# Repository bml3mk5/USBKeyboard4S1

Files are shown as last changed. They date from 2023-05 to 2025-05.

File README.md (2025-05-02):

# USBキーボード for 日立 MB-S1

## フォルダ構成

    Board/ ......................... 基板設計
      KiCad/ ....................... KiCad Version 6  通常基板(DIPタイプを使用)
      EasyEDA/ ..................... EasyEDA 6.5      小型基板(表面実装)
    Software/ ...................... PICマイコン用ソフトウェア

### [ラズパイPico版はこちら](https://github.com/bml3mk5/USBKeyboard4S1_PiPico)

-----
# USBKeyboard for HITACHI MB-S1

## Folders:

    Board/ ......................... Circuit board design
      KiCad/ ....................... KiCad Version 6  Normal board (using DIP type PIC micro controller)
      EasyEDA/ ..................... EasyEDA 6.5      Small board (using SMT type)
    Software/ ...................... Software for PIC micro controller

### [Raspberry Pi Pico version is here](https://github.com/bml3mk5/USBKeyboard4S1_PiPico)

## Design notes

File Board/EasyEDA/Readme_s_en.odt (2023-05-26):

USBKeyboard for S1 [S]

Designed by Sasaji 2023 Rev. 0.1

This is a converter to connect a USB Keyboard to HITACHI MB-S1 and LimeLight.

You can use a USB Keyboard with a HUB and a simple one.

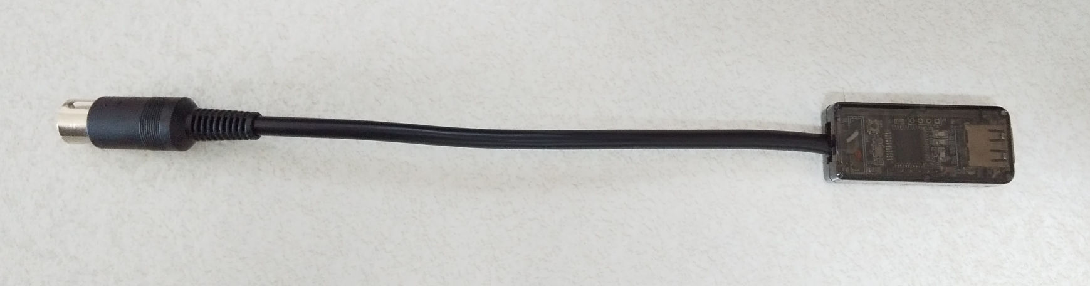
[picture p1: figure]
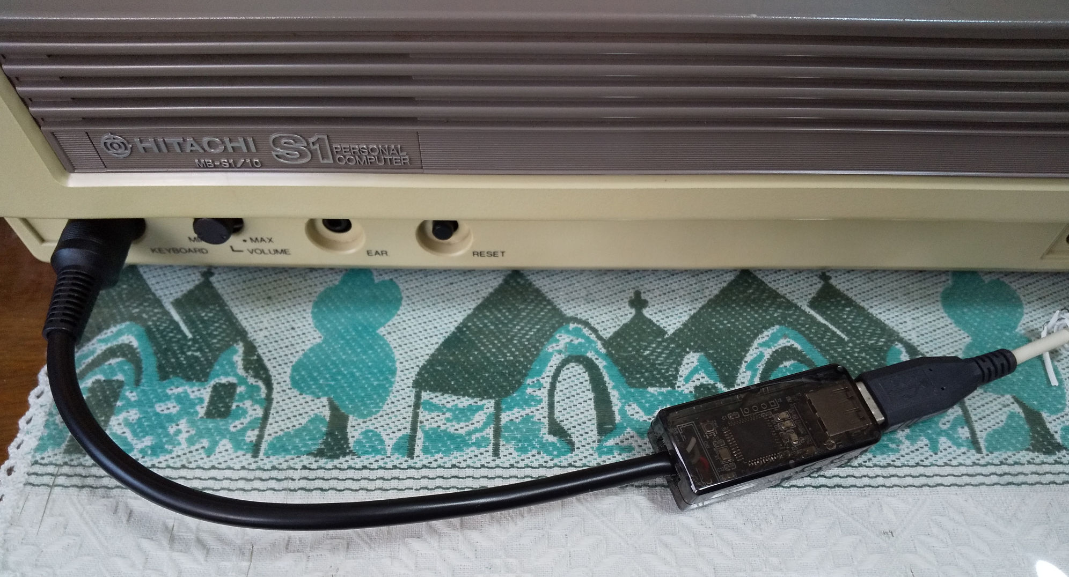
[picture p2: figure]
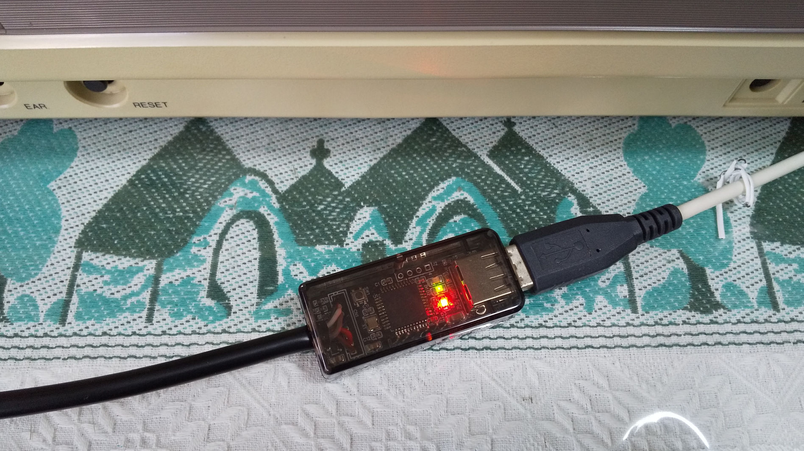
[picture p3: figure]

Example of the connection

Light the LED

# How To Use

1. Turn off the computer MB-S1.
2. Connect this device to the keyboard connector of MB-S1.
3. Connect a USB keyboard to this device.
4. Turn on the MB-S1.

When the USB keyboard is recognized, the green LED blinks about 3 times.

# Key Assign

Key assignment assumes a Japanese keyboard. We also recommend using a full keyboard.

These keys on the MB-S1 that are not on a USB keyboard are assigned as follows:

Table 1: Special key assignments

Key of MB-S1 | Key on USB Keyboard
[BREAK] | [F9]
[COPY] | [F12] / [PrintScreen]
[GRAPH] | [無変換] / [F7] / [Left Command]
[INS] | [Insert] / [F13]
[カタ/ひら] | [カタカナひらがな] / [F8] / [Right Command]
[変換] | [変換] / [F6]
[＿ロ] | [＿ろ] / [F11] / [Right ALT] / [Right Option]
[num ?] | [End]
[num ,] | [Page Down]

# LED on This Converter

# Red LED is ON when katakana is ON.

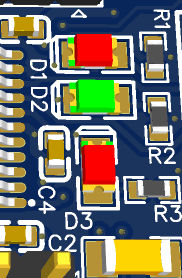
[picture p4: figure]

# Green LED is ON when hiragana is ON. Green LED blinks about 3 times when the USB keyboard is recognized.

# Red LED is ON when caps is ON.

# LED on a USB Keyboard

Num Lock → Turn on when katakana is ON.

Caps Lock → Turn on when caps is ON.

Scroll Lock → Turn on when hiragana is ON.

# The Board Information

UART Connector PIC microcontroller RESET Switch

PICKit Connector

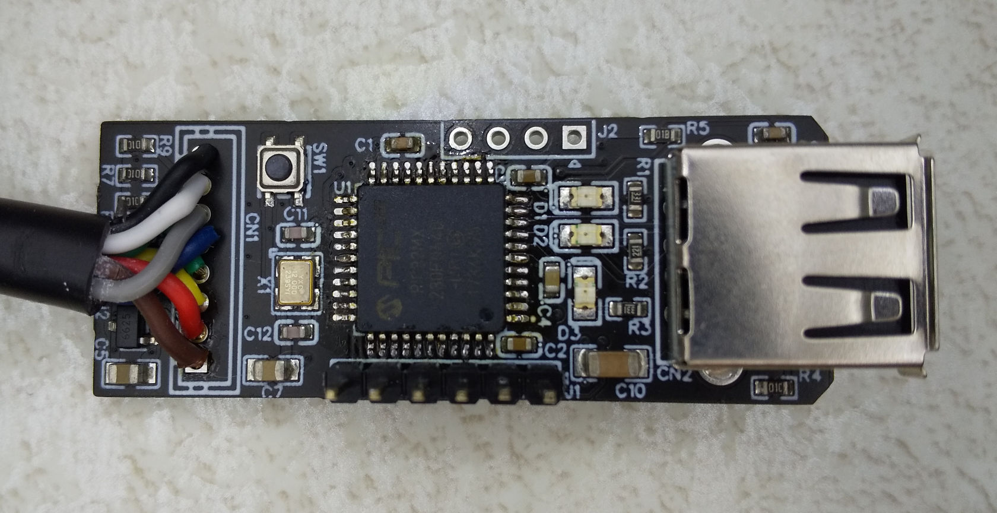
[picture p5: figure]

PIC microcontroller:

PIC32MX230F064D-I/PT

RESET Switch:

Initialize the PIC when you press this switch.

PICKit Connector:

Use for programming to the PIC.

Devices that can be connected are PICKit3, PICKit4 and compatibles.

These terminals are N/C, PGEC, PGED, GND, +3.3V, /MCLR from the left in the photo.

UART Connector:

Use for serial communication with the PIC. Nothing is outputted by default.

These terminals are GND, U1RX, U1TX, +5V from the left in the photo.

# Attention

- You can use only a wired keyboard and one with a HUB.
- Use a keyboard that supports USB1.1.
- This does not support a wireless keyboard or Bluetooth.
- Do not connect anything to ports on a HUB.
- Behavior is undefined when you connect a device other than a keyboard. In the worst case, the device may fail.
- Avoid connecting and disconnecting USB devices while the power is on.
- Do not disconnect this from the computer while the power is on.

# No Warranty

- This device is a prototype. Please note that we do not consider the noise generated during use or deterioration over time.
- We are not responsible for any damage caused by this device.

USE OF THIS EQUIPMENT IS AT YOUR OWN RISK.

# Web

This document and CAD data are available here:

http://s-sasaji.ddo.jp/bml3mk5/ (http://s-sasaji.ddo.jp/bml3mk5/s1usbkb.htm#smd)s1usbkb.htm (http://s-sasaji.ddo.jp/bml3mk5/s1usbkb.htm#smd)# (http://s-sasaji.ddo.jp/bml3mk5/s1usbkb.htm#smd)smd (http://s-sasaji.ddo.jp/bml3mk5/s1usbkb.htm#smd)

or

https://github.com/bml3mk5/USBKeyboard4S1

Sasaji (sasaji@s-sasaji.ddo.jp)

http://s-sasaji.ddo.jp/bml3mk5/

(Twitter: https://twitter.com/bml3mk5)

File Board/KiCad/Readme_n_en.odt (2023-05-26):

USBKeyboard for S1 [N]

Designed by Sasaji 2023 Rev. 0.1

This is a converter to connect a USB Keyboard to HITACHI MB-S1 and LimeLight.

You can use a USB Keyboard with a HUB and a simple one.

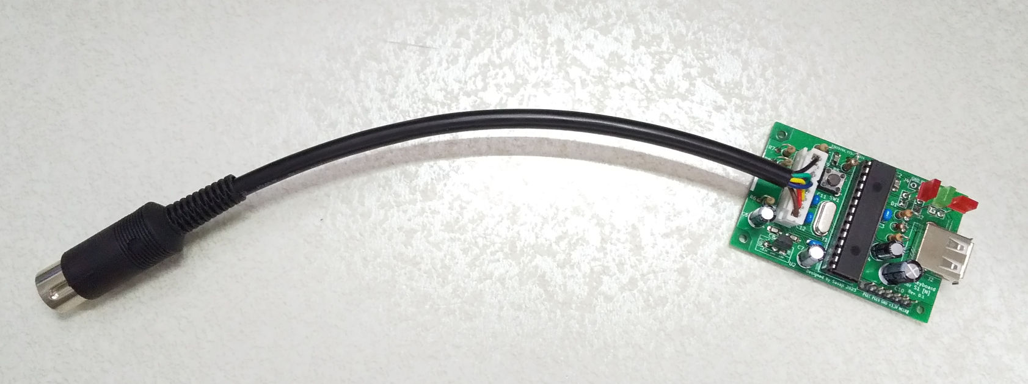
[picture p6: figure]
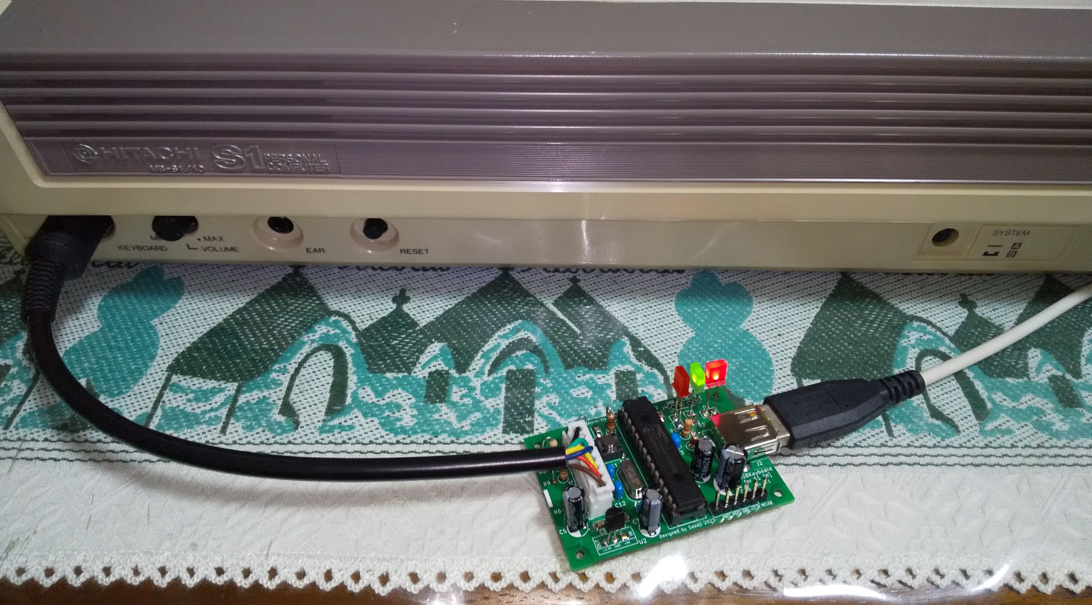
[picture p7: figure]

Example of the connection

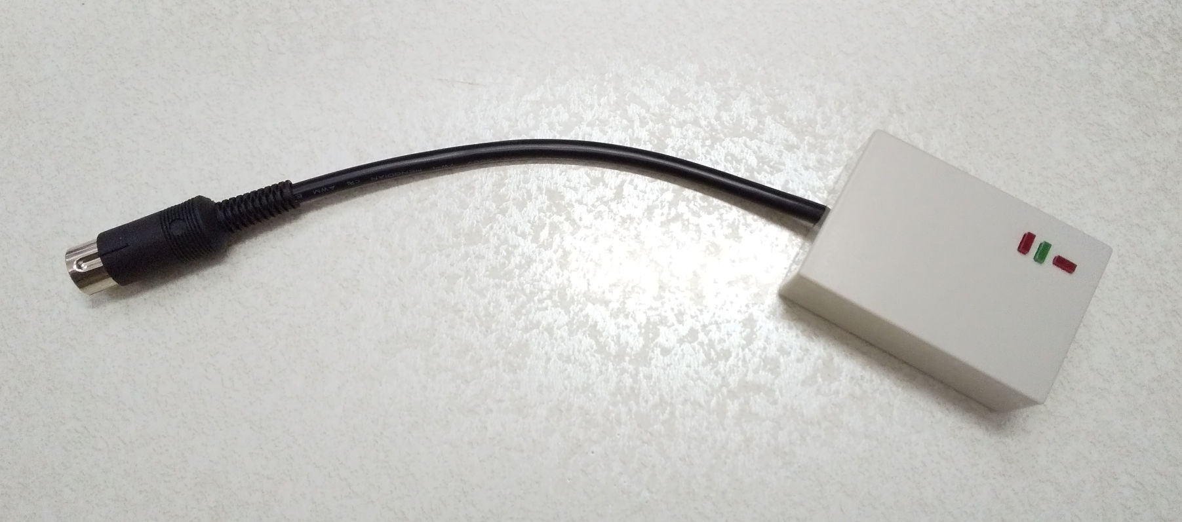
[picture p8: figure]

Housed in a case

# How To Use

1. Turn off the computer MB-S1.
2. Connect this device to the keyboard connector of MB-S1.
3. Connect a USB keyboard to this device.
4. Turn on the MB-S1.

When the USB keyboard is recognized, the green LED blinks about 3 times.

# Key Assign

Key assignment assumes a Japanese keyboard. We also recommend using a full keyboard.

These keys on the MB-S1 that are not on a USB keyboard are assigned as follows:

Table 1: Special key assignments

Key of MB-S1 | Key on USB Keyboard
[BREAK] | [F9]
[COPY] | [F12] / [PrintScreen]
[GRAPH] | [無変換] / [F7] / [Left Command]
[INS] | [Insert] / [F13]
[カタ/ひら] | [カタカナひらがな] / [F8] / [Right Command]
[変換] | [変換] / [F6]
[＿ロ] | [＿ろ] / [F11] / [Right ALT] / [Right Option]
[num ?] | [End]
[num ,] | [Page Down]

# LED on a USB Keyboard

Num Lock → Turn on when katakana is ON.

Caps Lock → Turn on when caps is ON.

Scroll Lock → Turn on when hiragana is ON.

# LED on This Converter

# Red LED is ON when katakana is ON.

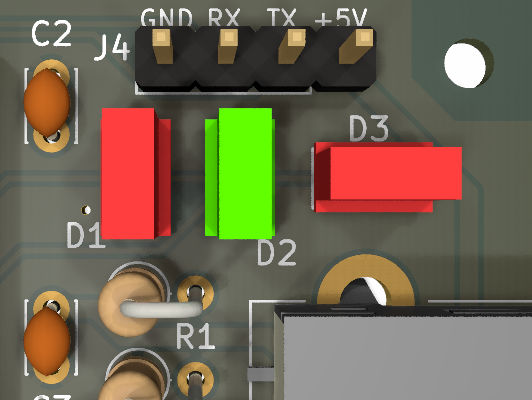
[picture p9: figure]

# Green LED is ON when hiragana is ON. Green LED blinks about 3 times when the USB keyboard is recognized.

# Red LED is ON when caps is ON.

# The Board Information

UART Connector PIC microcontroller RESET Switch

PICKit Connector

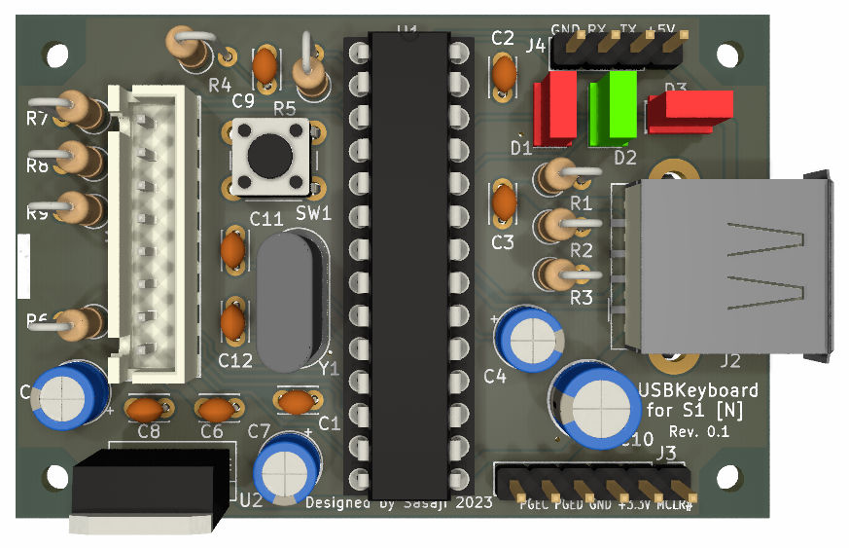
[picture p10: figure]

PIC microcontroller:

PIC32MX230F064B

RESET Switch:

Initialize the PIC when you press this switch.

PICKit Connector:

Use for programming to the PIC.

Devices that can be connected are PICKit3, PICKit4 and compatibles.

These terminals are N/C, PGEC, PGED, GND, +3.3V, /MCLR from the left in the photo.

UART Connector:

Use for serial communication with the PIC. Nothing is outputted by default.

These terminals are GND, U1RX, U1TX, +5V from the left in the photo.

# Attention

- You can use only a wired keyboard and one with a HUB.
- Use a keyboard that supports USB1.1.
- This does not support a wireless keyboard or Bluetooth.
- Do not connect anything to ports on a HUB.
- Behavior is undefined when you connect a device other than a keyboard. In the worst case, the device may fail.
- Avoid connecting and disconnecting USB devices while the power is on.
- Do not disconnect this from the computer while the power is on.

# No Warranty

- This device is a prototype. Please note that we do not consider the noise generated during use or deterioration over time.
- We are not responsible for any damage caused by this device.
  USE OF THIS EQUIPMENT IS AT YOUR OWN RISK.

# Web

This document and CAD data are available here:

http://s-sasaji.ddo.jp/bml3mk5/ (http://s-sasaji.ddo.jp/bml3mk5/s1usbkb.htm#board)s1usbkb.htm (http://s-sasaji.ddo.jp/bml3mk5/s1usbkb.htm#board)# (http://s-sasaji.ddo.jp/bml3mk5/s1usbkb.htm#board)board (http://s-sasaji.ddo.jp/bml3mk5/s1usbkb.htm#board)

or

https://github.com/bml3mk5/USBKeyboard4S1

Sasaji (sasaji@s-sasaji.ddo.jp)

http://s-sasaji.ddo.jp/bml3mk5/

(Twitter: https://twitter.com/bml3mk5)

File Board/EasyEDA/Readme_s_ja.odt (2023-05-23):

USBキーボード for S1 [S]

Designed by Sasaji 2023 Rev. 0.1

日立MB-S1または来夢来人とUSBキーボードを接続するための変換装置です。

USB Aコネクタのついたキーボードおよびハブ付きキーボードを接続することができます。


本体との接続例

LEDを点灯させたところ

# 使い方

1. MB-S1実機の電源をOFFにしてください。
2. 本装置をMB-S1実機のキーボード端子に接続してください。
3. 本装置にUSBキーボードを接続してください。
4. MB-S1実機の電源をONにしてください。

USBキーボードを認識すると緑色のLEDが3回ほど点滅します。

# キー操作

キーアサインは日本語キーボードを前提にしています。

また、フルキーボードの使用を推奨します。

S1にあってUSBキーボードにないキーについては以下のように割当てています。

表 1: 特殊なキーの割当て

S1側のキー | USBキーボード
[BREAK] | [F9]
[COPY] | [F12] / [PrintScreen]
[GRAPH] | [無変換] / [F7] / [左Command]
[INS] | [Insert] / [F13]
[カタ/ひら] | [カタカナひらがな] / [F8] / [右Command]
[変換] | [変換] / [F6]
[＿ロ] | [＿ろ] / [F11] / [右ALT] / [右Option]
[テンキー ?] | [End]
[テンキー ,] | [Page Down]

# 基板上のLED

# カタカナONのとき 赤色点灯


# ひらがなONのとき 緑色点灯 また、USBキーボードを 認識した時に 3回ほど点滅します。

# Caps ONのとき 赤色点灯

# キーボード側のLED

Num Lock → カタカナONのとき点灯

Caps Lock → Caps ONのとき点灯

Scroll Lock → ひらがなONのとき点灯

# ボードの情報

UART端子 PICマイコン RESETスイッチ

PICKit接続端子


PICマイコン

PIC32MX230F064D-I/PTを使用。

RESETスイッチ

押すとマイコンを初期状態に戻します。

PICKit接続端子

PICマイコンにプログラムを書き込む場合に使用します。

接続できる装置はPICKit3 / PICKit4 およびその互換機です。

端子は、写真左からN/C, PGEC, PGED, GND, +3.3V, /MCLR となります。

UART端子

PICマイコンとシリアル通信する場合に使用します。デフォルトでは何も出力されません。

端子は、写真左からGND, U1RX, U1TX, +5Vとなります。

# ご注意

- 対応しているのは有線のキーボード単体およびハブ付きキーボードです。
- USB1.1に対応しているキーボードを使用してください。
- 無線キーボードやBluetoothには対応していません。
- ハブのポートにはなにも接続しないでください。
- キーボード以外のデバイスを接続した時の動作は不定です。最悪デバイスが故障する可能性があります。
- 電源が入っている間はUSBデバイスの抜き差しはなるべく避けてください。
- 電源が入っている間はこの装置をパソコン本体から外さないでください。

# 免責事項

- この装置は試作品です。使用中に発生するノイズや経年劣化などに対しての考慮は全くしていませんので予めご了承ください。
- この装置によって発生したいかなる損害についても当方は一切責任を負いません。

この装置を使用するにあたってはすべて自己責任で行ってください。

# Webページ

この資料やCADデータなどを置いています。

http://s-sasaji.ddo.jp/bml3mk5/ (http://s-sasaji.ddo.jp/bml3mk5/s1usbkb.htm#smd)s1usbkb.htm (http://s-sasaji.ddo.jp/bml3mk5/s1usbkb.htm#smd)# (http://s-sasaji.ddo.jp/bml3mk5/s1usbkb.htm#smd)smd (http://s-sasaji.ddo.jp/bml3mk5/s1usbkb.htm#smd)

または

https://github.com/bml3mk5/USBKeyboard4S1

連絡先：

Sasaji (sasaji@s-sasaji.ddo.jp)

http://s-sasaji.ddo.jp/bml3mk5/

(Twitter: https://twitter.com/bml3mk5)

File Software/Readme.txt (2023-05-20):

==============================================================================
    USBキーボード -> MB-S1キーボード変換

 Copyright(C) Sasaji 2018-2023 All Rights Reserved.
==============================================================================

● 準備するもの

  マイコン: PIC32MX230F064B (DIP/SOP 28ピン)
  マイコンにプログラムできる装置(PICKit3,PICKit4など)

● 使い方

    dist/PIC32MX230F064B/production/USBKeyboard4S1.X.production.hex を、
  MPLAB IPEなどでマイコンに書き込んでください。

    ビルドは、MPLAB X Ver.6.05を使用しました。
      コンパイラ：XC32 v4.21

● キー操作

  キーアサインは日本語キーボードを前提にしています。
  また、フルキーボードの使用を推奨します。

  S1にあってUSBキーボードにないキーについては以下のように割当てています。

  S1側          USBキーボード
  ------------- ---------------------------------------
  [BREAK]       [F9]
  [COPY]        [F12] / [PrintScreen]
  [GRAPH]       [無変換] / [F7] / [左Command]
  [INS]         [Insert] / [F13]
  [カタ/ひら]   [カタカナひらがな] / [F8] / [右Command]
  [変換]        [変換] / [F6]
  [＿ロ]        [＿ろ] / [F11] / [右ALT] / [右Option]
  [テンキー ?]  [End]
  [テンキー ,]  [Page Down]

● キーボードLED

  Num Lock    → カタカナのとき点灯
  Caps Lock   → Caps ONのとき点灯
  Scroll Lock → ひらがなのとき点灯

● ご注意

  ・対応しているのは有線のキーボード単体およびハブ付きキーボードです。
  ・USB1.1に対応しているキーボードを使用してください。
  ・無線キーボードやBluetoothには対応していません。
  ・ハブのポートにはなにも接続しないでください。
  ・電源が入っている状態でのUSBデバイス抜き差しはなるべく避けてください。
  ・キーボード以外のデバイスを接続した時の動作は不定です。最悪デバイスが
    故障する可能性があります。

● 変更履歴

Version 0.2
	ハブ付きキーボードに対応
	英語キーボードにないキーを別のキーに割り当てた。
Version 0.1
	初期

● 免責事項

・このソースの著作権は作者Sasajiにあります。
・このソースコードを使用して発生するいかなる結果も著作権者は一切責任を負いません。
・雑誌やネットなどに転載される場合、不特定多数の方に再配布を行う場合でも
  承諾の必要はありませんが、転載の旨をご連絡いただけたら幸いです。

==============================================================================

連絡先：
  Sasaji (sasaji@s-sasaji.ddo.jp)
    http://s-sasaji.ddo.jp/bml3mk5/

==============================================================================

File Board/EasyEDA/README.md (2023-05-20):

## 使い方：

  1. EasyEADエディタ上で、ドキュメントを開く: File -> Open -> EasyEDA...
  2. jsonファイルを選択して開く。ファイルのインポートを選択。
  3. 別名で保存する -> 保存先のプロジェクトを選択。

----------
## How to use：

  1. On EasyEDA editor, open the document via: File -> Open -> EasyEDA...
  2. Select the json file and import the file, then open it on the editor.
  3. Save As... -> Select a project to save it.

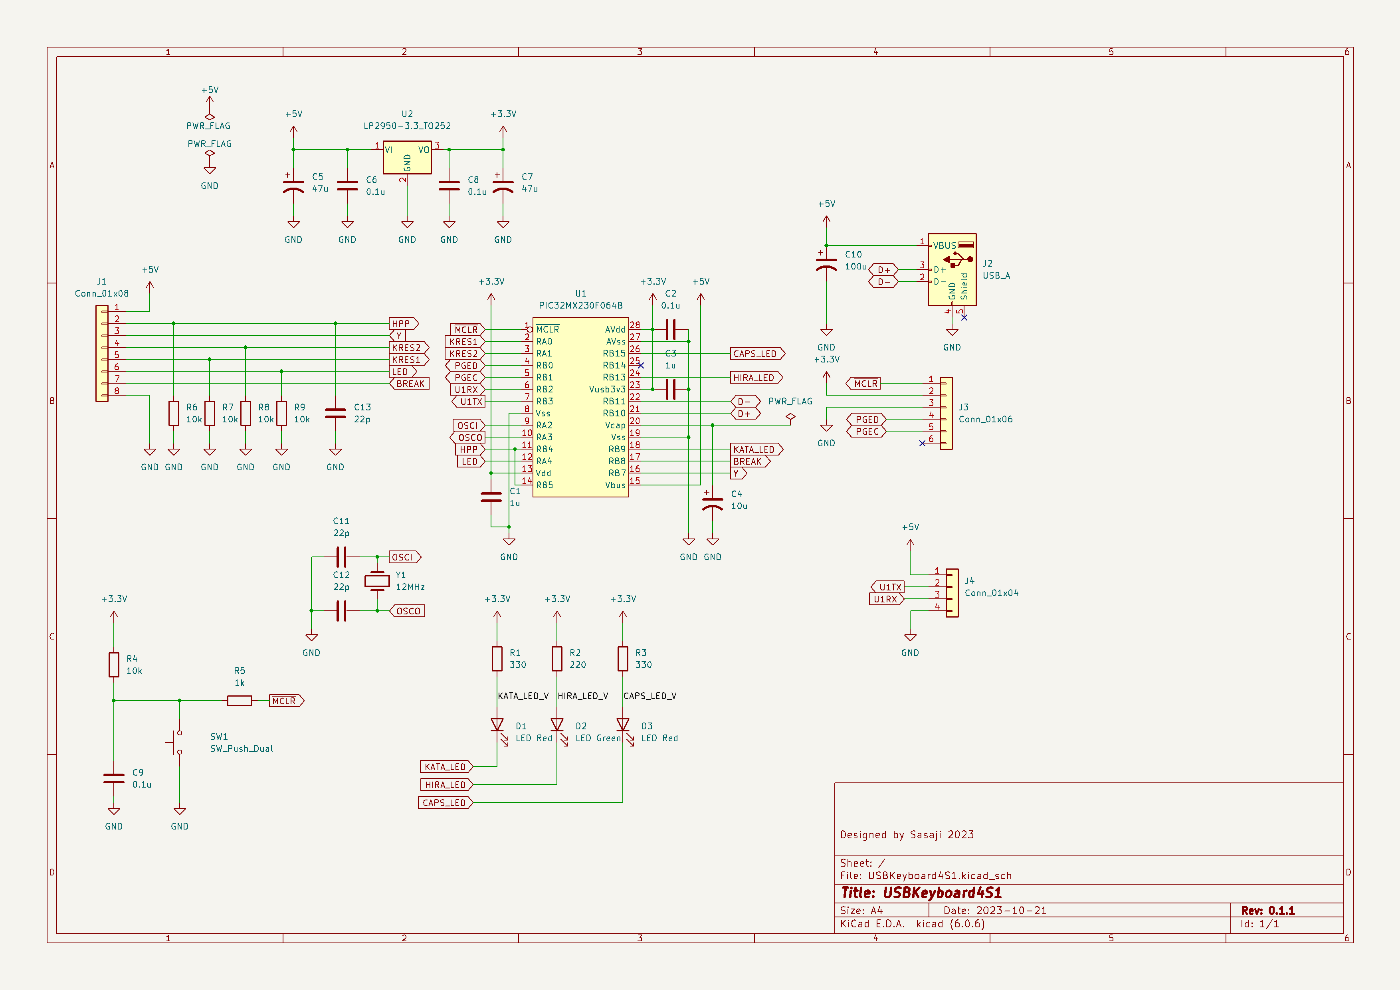
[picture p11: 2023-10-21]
Board/KiCad/Schematic.png

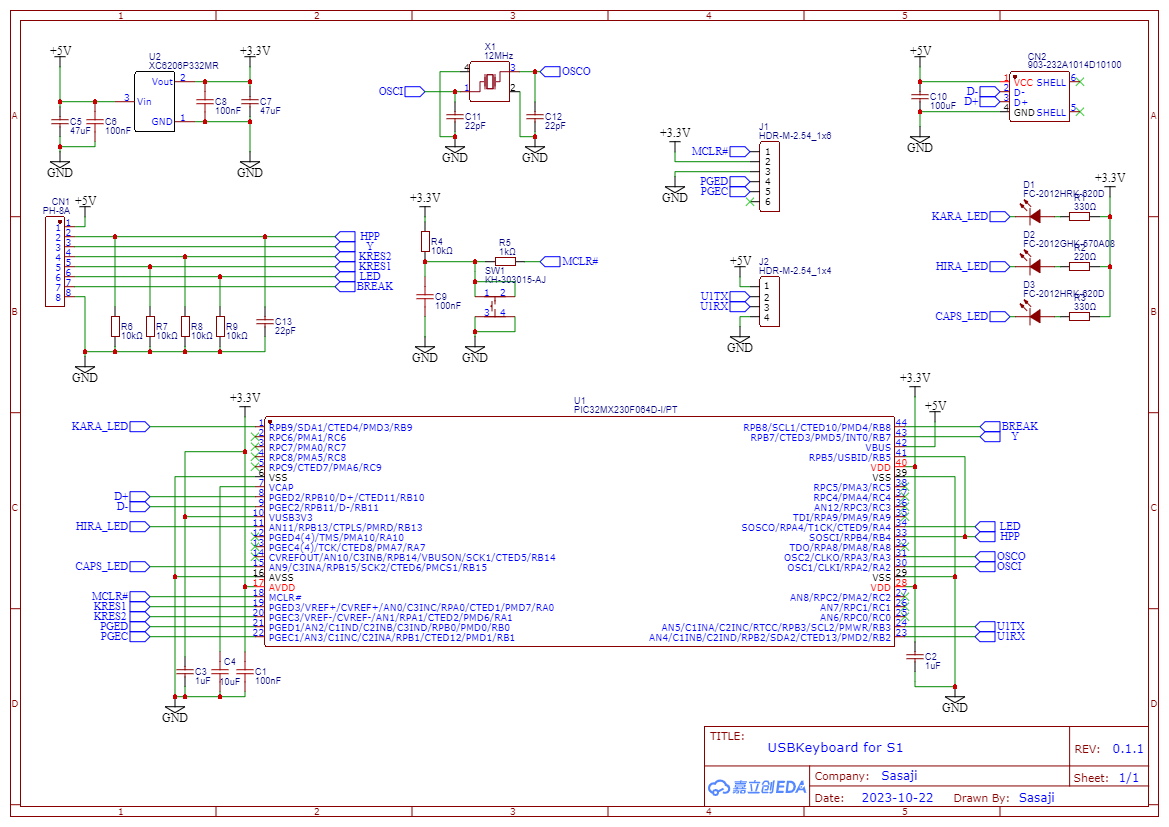
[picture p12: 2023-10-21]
Board/EasyEDA/Schematic.png

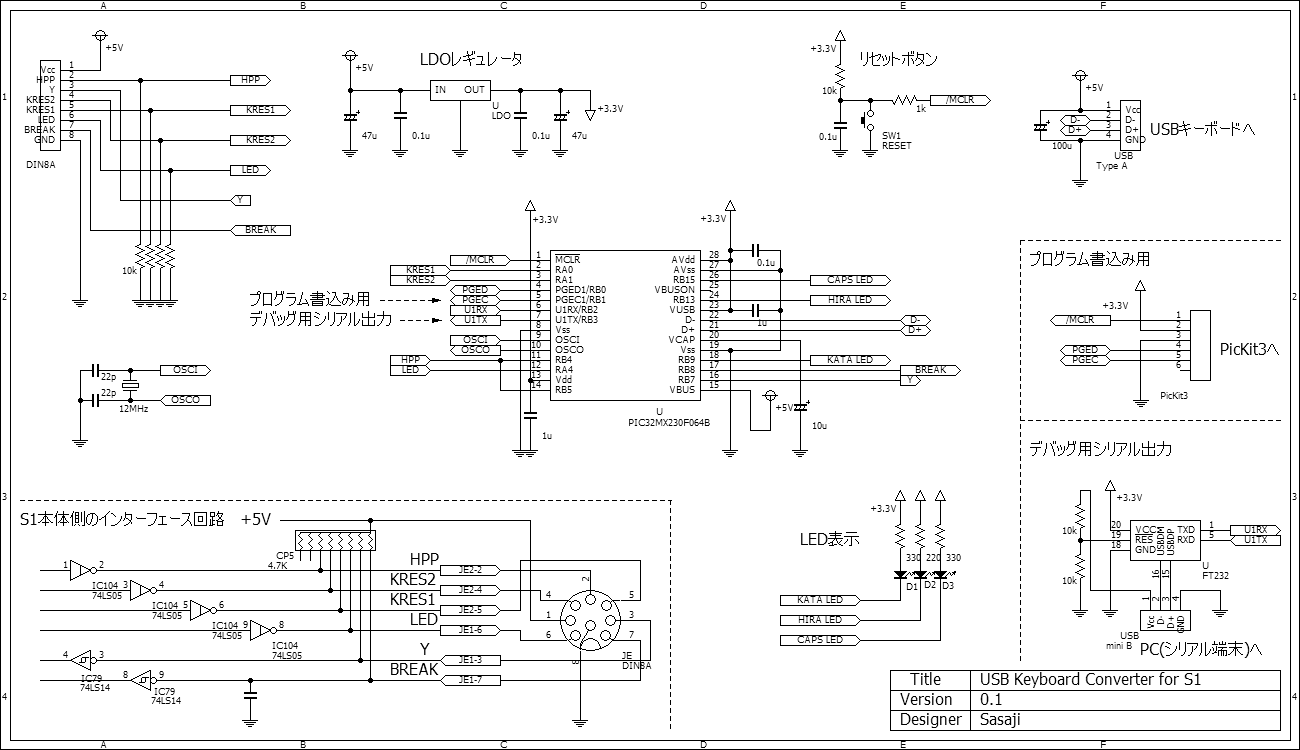
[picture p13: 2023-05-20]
Software/USBKeyboard4S1.X/Design/Circuit.png

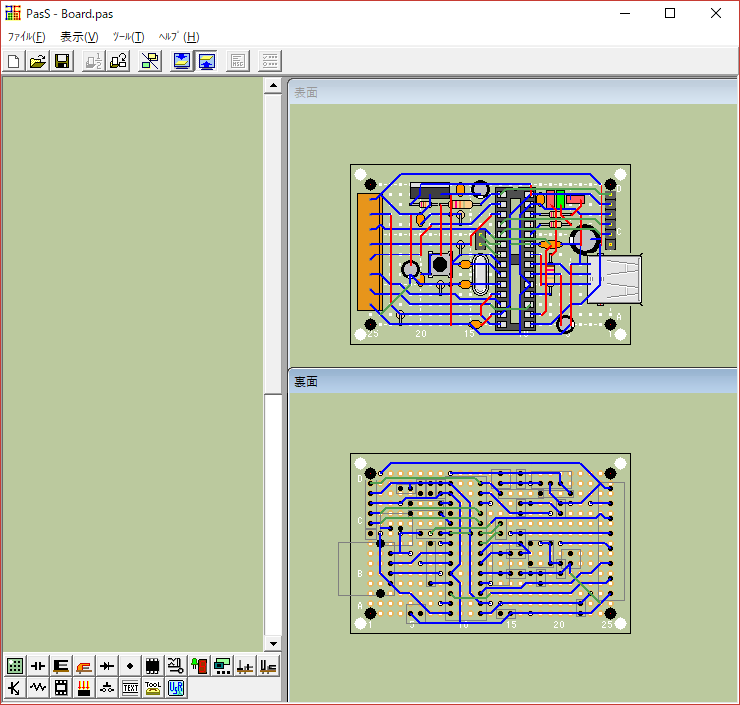
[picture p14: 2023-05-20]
Software/USBKeyboard4S1.X/Design/Board.png

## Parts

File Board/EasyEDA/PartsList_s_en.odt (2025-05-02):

USBKeyboard for S1 [S]

Designed by Sasaji 2023 Rev. 0.1.1

# Parts List

Parts Number | Parts Name | Qty. | Description | Usage
C1, C6, C8, C9 | Ceramic Capacitor | 4 | 0.1uF 0603mil | Bypass
C2, C3 | Ceramic Capacitor | 2 | 1uF 0603mil | Bypass
C4 | Ceramic Capacitor | 1 | 10uF 10V~ 0603mil | Bypass
C5, C7 | Ceramic Capacitor | 2 | 47uF 10V~ 0805mil | Bypass
C10 | Ceramic Capacitor | 1 | 100uF 10V~ 1206mil | Bypass
C11, C12 | Ceramic Capacitor | 2 | 22pF 0603mil | For clock
C13 | Ceramic Capacitor | 1 | 22pF 0603mil | Noise Removal
D1, D3 | LED (Red Color) | 2 | 0805mil
D2 | LED (Green Color) | 1 | 0805mil
J2 | USB A Connector | 1 | For circuit board
R1, R3 | Carbon Resistor | 2 | 330Ω 1/6W~ 0603mil | For Red LED
R2 | Carbon Resistor | 1 | 220Ω 1/6W~ 0603mil | For Green LED
R5 | Carbon Resistor | 1 | 1kΩ 1/6W~ 0603mil | Reset
R4 | Carbon Resistor | 1 | 10kΩ 1/6W~ 0603mil | Pullup
R6, R7, R8, R9 | Carbon Resistor | 4 | 10kΩ 1/6W~ 0603mil | Pulldown
SW1 | Tact Switch | 1 | 4pins 3.4 x 3.4mm Momentary | Reset
U1 | Pic Microcontroller | 1 | PIC32MX230F064D-I/PT TQFP 44
U2 | LDO Regurator | 1 | 5V to 3.3V SOT-23
Y1 | Crystal | 1 | 12MHz 4pins 3.2 x 2.5mm
J1 | Connector 6pins | 1 | Pinheader 1 x 6pins 2.54mm pitch | For PicKit
| DIN connector 8pins | 1 | 8pins Type A male (MP-018 etc.) | Connect to a PC.
| Multicore Cable | 1 | 8cores AWM24 or 26 Outer diameter is less than 6mm. [^1]

  Optional Parts

Parts Number | Parts Name | Qty. | Description | Usage
J2 | Connector 4pins | 1 | Pinheader 1 x 4pins 2.54mm pitch | For UART
| Case | 1 | 53 x 24 x 14mm (AK-N-12)

DIN8pins male assign:

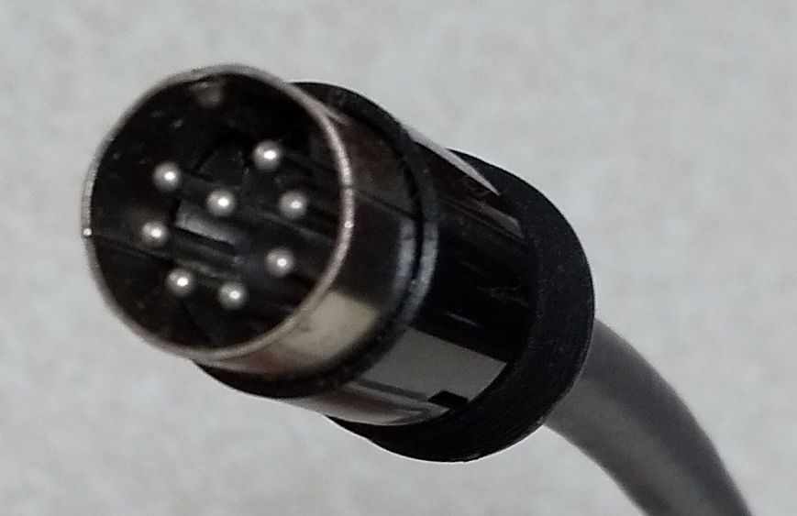
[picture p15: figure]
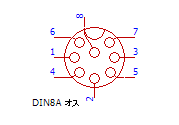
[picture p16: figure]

# Warnings when housing the board in a case

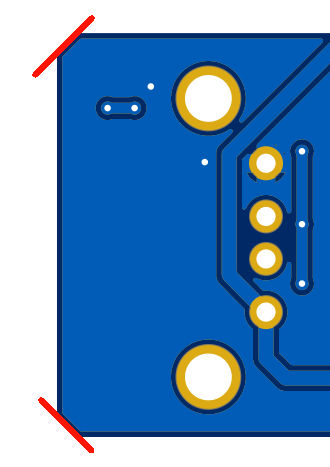
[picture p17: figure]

1. If the board does not fit in the case, cut off the slanted part a little.
2. You must connect the multicore cable directly to the board. If you use a PH connector, it will not fit in a case due to its height.
3. The height of the component side of the board should be about 8.5mm, and the height of the solder side should be about 1.5mm. (When thickness of the board is 1.6mm)

# How to Program to The Microcontroller

1. Connect a Programmer and Power supply to the circuit board.
  a. Connect a programmer (PICKit3/4) to J1 on the board.
  b. Connect a +5V Power supply to J2 or USB connector. When use the USB connector, don’t connect to the data line (D+,D-).

+5V Power Supply: USB Connector or J2 Connector

Programmer (PICKit3/4)


2. Program to PIC microcontroller using MPLAB IPE.
- Select a Device: PIC32MX230F064D
- Select a HEX file:

USBKeyboard4S1.X\dist\PIC32MX230F064D_I\production\USBKeyboard4S1.X.production.hex

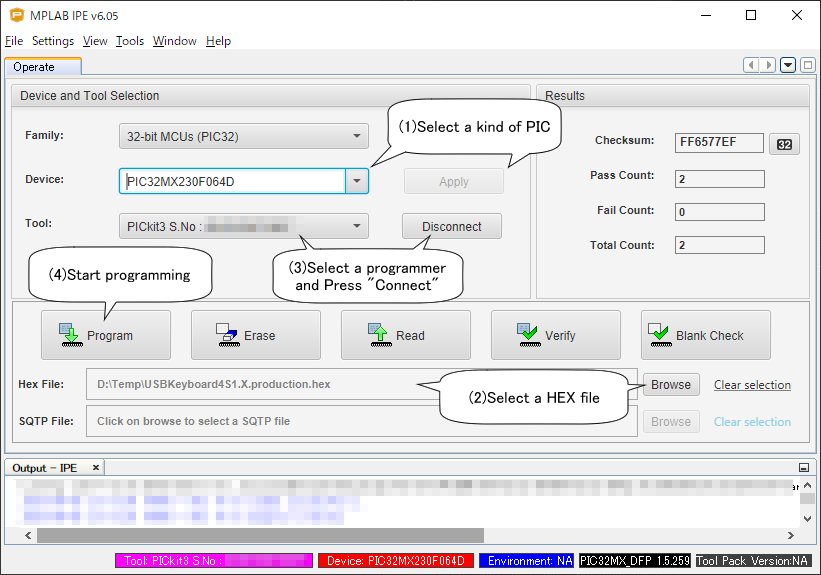
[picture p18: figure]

If succeed the programming, The Red LED(Caps) on the board is brighten.

# Web

There are this document and a CAD data on the web:

http://s-sasaji.ddo.jp/bml3mk5/ (http://s-sasaji.ddo.jp/bml3mk5/s1usbkb.htm#smd)s1usbkb.htm (http://s-sasaji.ddo.jp/bml3mk5/s1usbkb.htm#smd)# (http://s-sasaji.ddo.jp/bml3mk5/s1usbkb.htm#smd)smd (http://s-sasaji.ddo.jp/bml3mk5/s1usbkb.htm#smd)

or

https://github.com/bml3mk5/USBKeyboard4S1

Sasaji (sasaji@s-sasaji.ddo.jp)

http://s-sasaji.ddo.jp/bml3mk5/

(Twitter: https://twitter.com/bml3mk5)

[^1] If the outer diameter is more than 6mm , it will not pass in a bush of a DIN connector.

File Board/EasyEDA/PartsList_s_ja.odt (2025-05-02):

USBキーボード for S1 [S]

Designed by Sasaji 2023 Rev. 0.1.1

# 部品表

番号 | 部品名 | 数量 | 値など | 用途
C1, C6, C8, C9 | セラミックコンデンサ | 4 | 0.1uF 0603mil | パスコン
C2, C3 | セラミックコンデンサ | 2 | 1uF 0603mil | パスコン
C4 | セラミックコンデンサ | 1 | 10uF 10V以上 0603mil | パスコン
C5, C7 | セラミックコンデンサ | 2 | 47uF 10V以上 0805mil | パスコン
C10 | セラミックコンデンサ | 1 | 100uF 10V以上 1206mil | パスコン
C11, C12 | セラミックコンデンサ | 2 | 22pF 0603mil | クロック生成
C13 | セラミックコンデンサ | 1 | 22pF 0603mil | ノイズ対策
D1, D3 | LED 赤色 | 2 | 0805mil
D2 | LED 緑色 | 1 | 0805mil
J2 | USB Aコネクタ | 1 | 基板取付用
R1, R3 | カーボン抵抗 | 2 | 330Ω 1/6W～ 0603mil | 赤LED用
R2 | カーボン抵抗 | 1 | 220Ω 1/6W～ 0603mil | 緑LED用
R5 | カーボン抵抗 | 1 | 1kΩ 1/6W～ 0603mil | リセット用
R4 | カーボン抵抗 | 1 | 10kΩ 1/6W～ 0603mil | プルアップ
R6, R7, R8, R9 | カーボン抵抗 | 4 | 10kΩ 1/6W～ 0603mil | プルダウン
SW1 | タクトスイッチ | 1 | 4ピン 3.4 x 3.4mm モーメンタリ | リセット
U1 | Picマイコン | 1 | PIC32MX230F064D-I/PT TQFP 44ピン
U2 | LDOリニアレギュレータ | 1 | 5V→ 3.3Vのもの SOT-23
Y1 | 水晶振動子 | 1 | 12MHz 4ピン 3.2 x 2.5mm
J1 | コネクタ 6ピン | 1 | ピンヘッダ 1 x 6ピン 2.54mmピッチ | PicKit接続端子
| DINコネクタ 8ピン | 1 | 8ピンAタイプ オス | 本体との接続
| 多芯ケーブル | 1 | 8芯 AWM24か26ぐらい 外径6mm未満[^1]

  以下はオプション

番号 | 部品名 | 数量 | 値など | 用途
J2 | コネクタ 4ピン | 1 | ピンヘッダ 1 x 4ピン 2.54mmピッチ | UART端子
| プラスチックケース | 1 | 53 x 24 x 14mm (秋月電子 AK-N-12 または Aitendo USBコネクタ適合プラケース [C53X24X14]) | 基板収納用

DIN8ピン オスのピン配置は以下になります。


# ケースに収める場合の注意点


1. 基板がケースに収まらない場合は、斜め部分を少し削ってください。
2. 多芯ケーブルは基板に直接接続してください。PHコネクタを使うと高さがあるためケースに収まらなくなります。
3. 基板の部品面の高さは8.5mmほど、ハンダ面の高さは1.5mmほどに収めてください。（基板の厚さを1.6mmとしたとき）

# マイコンへのプログラム方法

1. 基板に電源と書き込み装置を接続してください。
  a. J1端子に書き込み装置(PICKit3/4など)を接続してください。
  b. +5V電源をUSB端子またはJ2端子にある+5VとGNDに接続してください。USB端子を使用する場合、データライン(D+,D-)には接続しないようにしてください。

+5V電源は USB端子 または J2端子 を使用

書き込み装置 (PICKit3/4など)


2. MPLAB IPEなどを使用してマイコンにプログラムしてください。
- PICマイコンはPIC32MX230F064Dを選択。
- HEXファイルは

USBKeyboard4S1.X\dist\PIC32MX230F064D_I\production\USBKeyboard4S1.X.production.hex

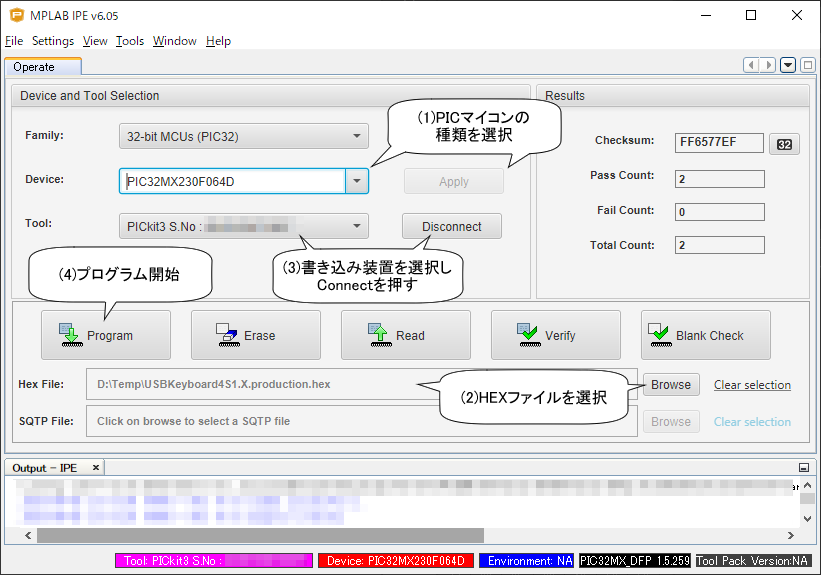
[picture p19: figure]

成功すると、基板上の赤色LED(Caps)が点灯します。

# Webページ

この資料やCADデータなどを置いています。

http://s-sasaji.ddo.jp/bml3mk5/ (http://s-sasaji.ddo.jp/bml3mk5/s1usbkb.htm#smd)s1usbkb.htm (http://s-sasaji.ddo.jp/bml3mk5/s1usbkb.htm#smd)# (http://s-sasaji.ddo.jp/bml3mk5/s1usbkb.htm#smd)smd (http://s-sasaji.ddo.jp/bml3mk5/s1usbkb.htm#smd)

または

https://github.com/bml3mk5/USBKeyboard4S1

連絡先：

Sasaji (sasaji@s-sasaji.ddo.jp)

http://s-sasaji.ddo.jp/bml3mk5/

(Twitter: https://twitter.com/bml3mk5)

[^1] 外径が6mmを超えるとDINコネクタのブッシュを通らなくなります。

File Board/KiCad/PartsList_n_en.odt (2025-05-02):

USBKeyboard for S1 [N]

Designed by Sasaji 2023 Rev. 0.1.1

# Parts List

Parts Number | Parts Name | Qty. | Description | Usage
C2, C6, C8, C9 | Ceramic Capacitor | 4 | 0.1uF | Bypass
C1, C3 | Ceramic Capacitor | 2 | 1uF | Bypass
C4 | Electrolytic Capacitor | 1 | 10uF 10V~ | Bypass
C5, C7 | Electrolytic Capacitor | 2 | 47uF 10V~ | Bypass
C10 | Electrolytic Capacitor | 1 | 100uF 10V~ | Bypass
C11, C12 | Ceramic Capacitor | 2 | 22pF | For clock
C13 | Ceramic Capacitor | 1 | 22pF | Noise Removal
D1, D3 | LED (Red Color) | 2 | Rectangle 2 x 5 x 7mm
D2 | LED (Green Color) | 1 | Rectangle 2 x 5 x 7mm
J2 | USB A Connector | 1 | For circuit board
R1, R3 | Carbon Resistor | 2 | 330Ω 1/4W | For Red LED
R2 | Carbon Resistor | 1 | 220Ω 1/4W | For Green LED
R5 | Carbon Resistor | 1 | 1kΩ 1/4W | Reset
R4 | Carbon Resistor | 1 | 10kΩ 1/4W | Pullup
R6, R7, R8, R9 | Carbon Resistor | 4 | 10kΩ 1/4W | Pulldown
SW1 | Tact Switch | 1 | 6 x 5mm Momentary | Reset
U1 | Pic Microcontroller | 1 | PIC32MX230F064B [^1] DIP 28
U2 | LDO Regurator | 1 | 5V→ 3.3V / 100mA (LM2940,LP2950 etc.)
Y1 | Crystal | 1 | 12MHz
J1 | Connector 8pins | 1 | JST XH 1 x 8pins 2.5mm pitch male | Connect between a cable and the board. * It’s not necessary if connect a cable directly.
| Connector 8pins Housing | 1 | JST XH 1 x 8pins 2.5mm pitch female
| Pins | 8 | For XH connector
J3 | Connector 6pins | 1 | Pinheader 1 x 6pins 2.54mm pitch | For PicKit
| DIN connector 8pins | 1 | 8pins Type A male (MP-018 etc.) | Connect to a PC.
| Multicore Cable | 1 | 8cores AWM24 or 26 Outer diameter is less than 6mm. [^2]

Optional Parts

Parts Number | Parts Name | Qty. | Description | Usage
J4 | Connector 4pins | 1 | Pinheader 1 x 4pins 2.54mm pitch | For UART
| IC Socket | 1 | DIP 28 300mil
| Case | 1 | 45 x 65mm (TAKACHI SW-65 etc.)
| Screws | 4 | M2 x 8mm
| Nuts | 4
| Washers | 4

DIN8pins male assign:


# How to Program to The Microcontroller

1. Connect a Programmer and Power supply to the circuit board.
  a. Connect a programmer (PICKit3/4) to J3 on the board.
  b. Connect a +5V Power supply to J4 or USB connector. When use the USB connector, don’t connect to the data line (D+,D-).


Programmer (PICKit3/4) +5V Power supply: USB connector or J4 connector

2. Program to PIC microcontroller using MPLAB IPE.
- Select a Device: PIC32MX230F064B
- Select a HEX file:

USBKeyboard4S1.X\dist\PIC32MX230F064B\production\USBKeyboard4S1.X.production.hex

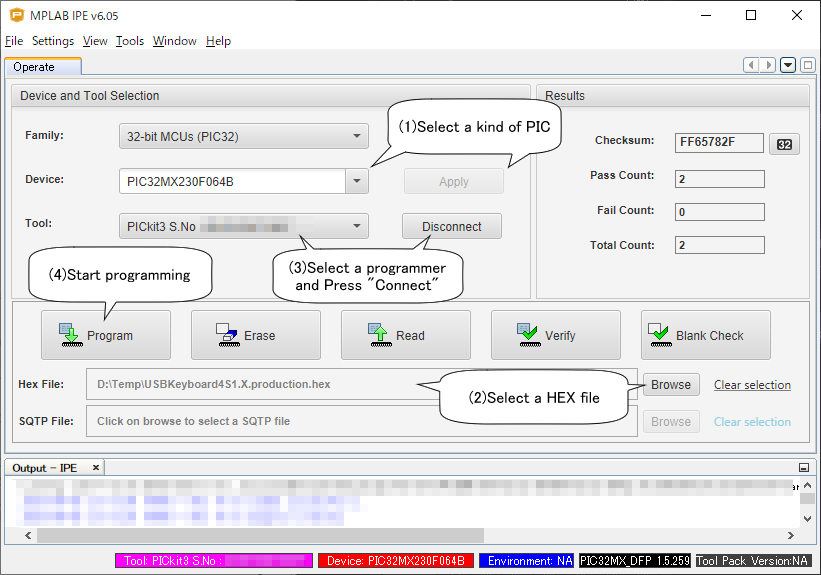
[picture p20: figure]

If succeed the programming, The Red LED(Caps) on the board is brighten.

# Web

There are this document and a CAD data on the web:

http://s-sasaji.ddo.jp/bml3mk5/ (http://s-sasaji.ddo.jp/bml3mk5/s1usbkb.htm#board)s1usbkb.htm (http://s-sasaji.ddo.jp/bml3mk5/s1usbkb.htm#board)# (http://s-sasaji.ddo.jp/bml3mk5/s1usbkb.htm#board)board (http://s-sasaji.ddo.jp/bml3mk5/s1usbkb.htm#board)

or

https://github.com/bml3mk5/USBKeyboard4S1

Sasaji (sasaji@s-sasaji.ddo.jp)

http://s-sasaji.ddo.jp/bml3mk5/

(Twitter: https://twitter.com/bml3mk5)

[^1] You can use PIC32MX2xxFxxxB series.
[^2] If the outer diameter is more than 6mm , it will not pass in a bush of a DIN connector.

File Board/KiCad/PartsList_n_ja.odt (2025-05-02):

USBキーボード for S1 [N]

Designed by Sasaji 2023 Rev. 0.1.1

# 部品表

番号 | 部品名 | 数量 | 値など | 用途
C2, C6, C8, C9 | セラミックコンデンサ | 4 | 0.1uF | パスコン
C1, C3 | セラミックコンデンサ | 2 | 1uF | パスコン
C4 | 電解コンデンサ | 1 | 10uF 10V以上 | パスコン
C5, C7 | 電解コンデンサ | 2 | 47uF 10V以上 | パスコン
C10 | 電解コンデンサ | 1 | 100uF 10V以上 | パスコン
C11, C12 | セラミックコンデンサ | 2 | 22pF | クロック生成
C13 | セラミックコンデンサ | 1 | 22pF | ノイズ対策
D1, D3 | LED 赤色 | 2 | 角型 2 x 5 x 7mm
D2 | LED 緑色 | 1 | 角型 2 x 5 x 7mm
J2 | USB Aコネクタ | 1 | 基板取付用
R1, R3 | カーボン抵抗 | 2 | 330Ω 1/4W | 赤LED用
R2 | カーボン抵抗 | 1 | 220Ω 1/4W | 緑LED用
R5 | カーボン抵抗 | 1 | 1kΩ 1/4W | リセット用
R4 | カーボン抵抗 | 1 | 10kΩ 1/4W | プルアップ
R6, R7, R8, R9 | カーボン抵抗 | 4 | 10kΩ 1/4W | プルダウン
SW1 | タクトスイッチ | 1 | 6 x 5mm モーメンタリ | リセット
U1 | Picマイコン | 1 | PIC32MX230F064B[^1] DIP 28ピン
U2 | LDO 3端子レギュレータ | 1 | 5V→ 3.3Vのもの100mA (LM2940,LP2950など)
Y1 | 水晶振動子 | 1 | 12MHz
J1 | コネクタ 8ピン | 1 | JST XHコネクタ 1 x 8ピン 2.5mmピッチ オス | 多芯ケーブルと基板との接続 ※多芯ケーブルを直接基板に取り付ける場合は不要。
| コネクタ 8ピン ハウジング | 1 | JST XHコネクタ 1 x 8ピン 2.5mmピッチ メス
| コネクタ用ピン | 8 | 上記XHコネクタ用ピン
J3 | コネクタ 6ピン | 1 | ピンヘッダ 1 x 6ピン 2.54mmピッチ | PicKit接続端子
| DINコネクタ 8ピン | 1 | 8ピンAタイプ オス (マル信無線電機MP-018など) | 本体との接続
| 多芯ケーブル | 1 | 8芯 AWM24か26ぐらい 外径 6mm未満[^2]

以下はオプション

番号 | 部品名 | 数量 | 値など | 用途
J4 | コネクタ 4ピン | 1 | ピンヘッダ 1 x 4ピン 2.54mmピッチ | UART端子
| ICソケット | 1 | DIP 28ピン 300mil
| プラスチックケース | 1 | 45 x 65mm (タカチ SW-65など) | 基板収納用
| なべ小ねじ | 4 | M2 x 8mm以上 | 基板をケースに固定
| ナット | 4 | 上記ネジ用
| ワッシャ | 4 | 上記ネジ用

DIN8ピン オスのピン配置は以下になります。


# マイコンへのプログラム方法

1. 基板に電源と書き込み装置を接続してください。
  a. J3端子に書き込み装置(PICKit3/4など)を接続してください。
  b. +5V電源をUSB端子またはJ4端子にある+5VとGNDに接続してください。USB端子を使用する場合、データライン(D+,D-)には接続しないようにしてください。


書き込み装置 (PICKit3/4など) +5V電源は USB端子 または J4端子 を使用

2. MPLAB IPEなどを使用してマイコンにプログラムしてください。
- PICマイコンはPIC32MX230F064Bを選択。
- HEXファイルは

USBKeyboard4S1.X\dist\PIC32MX230F064B\production\USBKeyboard4S1.X.production.hex

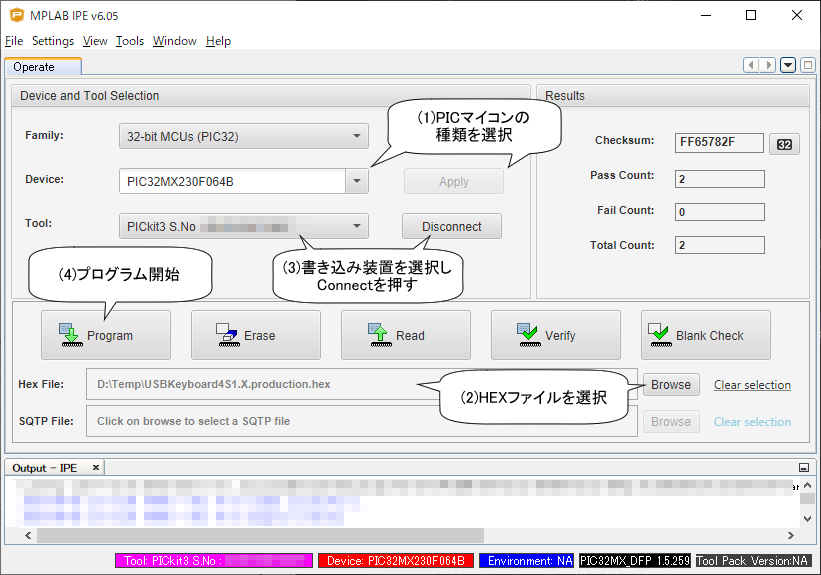
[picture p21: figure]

成功すると、基板上の赤色LED(Caps)が点灯します。

# Webページ

この資料やCADデータなどを置いています。

http://s-sasaji.ddo.jp/bml3mk5/ (http://s-sasaji.ddo.jp/bml3mk5/s1usbkb.htm#board)s1usbkb.htm (http://s-sasaji.ddo.jp/bml3mk5/s1usbkb.htm#board)# (http://s-sasaji.ddo.jp/bml3mk5/s1usbkb.htm#board)board (http://s-sasaji.ddo.jp/bml3mk5/s1usbkb.htm#board)

または

https://github.com/bml3mk5/USBKeyboard4S1

連絡先：

Sasaji (sasaji@s-sasaji.ddo.jp)

http://s-sasaji.ddo.jp/bml3mk5/

(Twitter: https://twitter.com/bml3mk5)

[^1] PIC32MX2xxFxxxBシリーズが使用できます。
[^2] 外径が6mmを超えるとDINコネクタのブッシュを通らなくなります。

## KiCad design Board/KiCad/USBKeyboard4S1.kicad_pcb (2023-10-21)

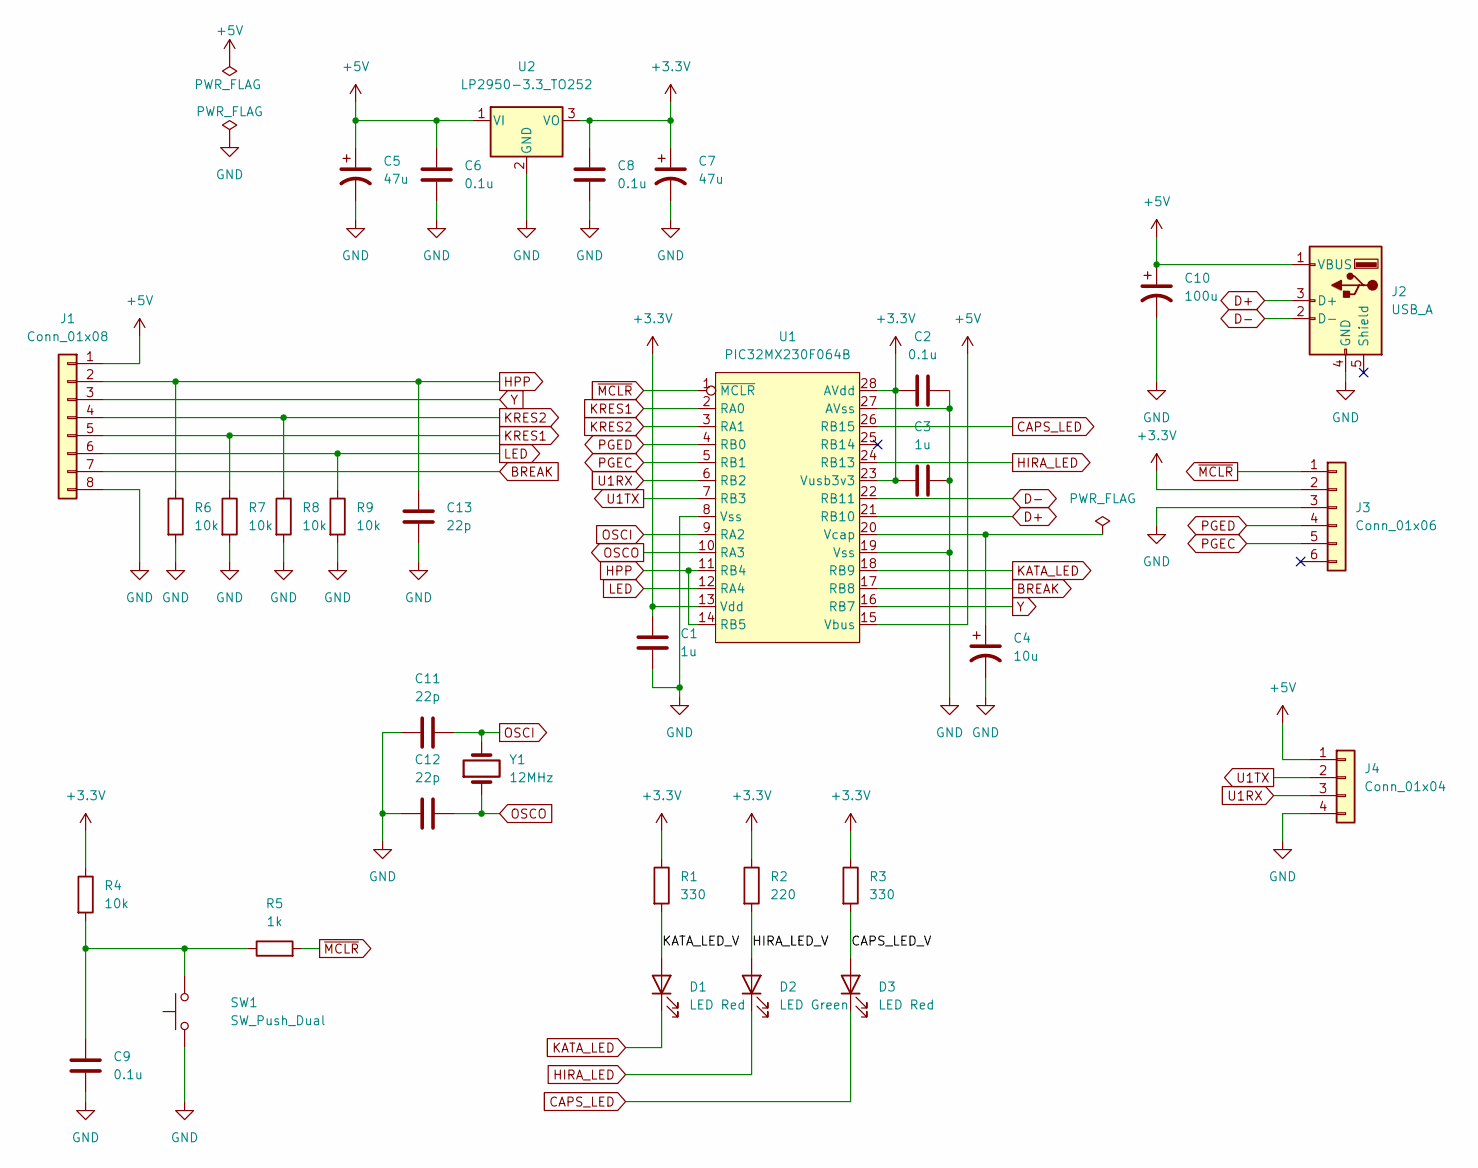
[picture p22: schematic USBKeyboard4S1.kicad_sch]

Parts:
C1, C3: 1u; C_Disc_D3.0mm_W2.0mm_P2.50mm
C2, C6, C8, C9: 0.1u; C_Disc_D3.0mm_W2.0mm_P2.50mm
C4: 10u; CP_Radial_D5.0mm_P2.50mm
C5, C7: 47u; CP_Radial_D5.0mm_P2.50mm
C10: 100u; CP_Radial_D6.3mm_P2.50mm
C11, C12, C13: 22p; C_Disc_D3.0mm_W2.0mm_P2.50mm
D1, D3: LED Red; LED_D2.0mm_W4.8mm_H2.5mm_FlatTop
D2: LED Green; LED_D2.0mm_W4.8mm_H2.5mm_FlatTop
J1: Conn_01x08; JST_XH_B8B-XH-A_1x08_P2.50mm_Vertical
J2: USB_A; USB_A_Horizontal
J3: Conn_01x06; PinHeader_1x06_P2.54mm_Vertical
J4: Conn_01x04; PinHeader_1x04_P2.54mm_Vertical
R1, R3: 330; R_Axial_DIN0207_L6.3mm_D2.5mm_P2.54mm_Vertical
R2: 220; R_Axial_DIN0207_L6.3mm_D2.5mm_P2.54mm_Vertical
R4, R6, R7, R8, R9: 10k; R_Axial_DIN0207_L6.3mm_D2.5mm_P2.54mm_Vertical
R5: 1k; R_Axial_DIN0207_L6.3mm_D2.5mm_P2.54mm_Vertical
SW1: SW_Push_Dual; SW_PUSH_6mm
U1: PIC32MX230F064B; DIP-28_W7.62mm_Socket
U2: LP2950-3.3_TO252; TO-262-3_Vertical
Y1: 12MHz; Crystal_HC18-U_Vertical

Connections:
+3.3V: C1.1, C2.1, C3.1, C7.1, C8.2, J3.2, R1.1, R2.1, R3.1, R4.1, U1.13 (Vdd), U1.23 (Vusb3v3), U1.28 (AVdd), U2.3 (VO)
+5V: C5.1, C6.2, C10.1, J1.1, J2.1 (VBUS), J4.1, U1.15 (Vbus), U2.1 (VI)
/CAPS_LED_V: D3.1 (A), R3.2
/HIRA_LED_V: D2.1 (A), R2.2
/KATA_LED_V: D1.1 (A), R1.2
BREAK: J1.7, U1.17 (RB8)
CAPS_LED: D3.2 (K), U1.26 (RB15)
D+: J2.3 (D+), U1.21 (RB10)
D-: J2.2 (D-), U1.22 (RB11)
GND: C1.2, C2.2, C3.2, C4.2, C5.2, C6.1, C7.2, C8.1, C9.1, C10.2, C11.1, C12.1, C13.1, J1.8, J2.4 (GND), J3.3, J4.4, R6.2, R7.2, R8.2, R9.2, SW1.1, U1.8 (Vss), U1.19 (Vss), U1.27 (AVss), U2.2 (GND)
HIRA_LED: D2.2 (K), U1.24 (RB13)
HPP: C13.2, J1.2, R6.1, U1.11 (RB4), U1.14 (RB5)
KATA_LED: D1.2 (K), U1.18 (RB9)
KRES1: J1.5, R7.1, U1.2 (RA0)
KRES2: J1.4, R8.1, U1.3 (RA1)
LED: J1.6, R9.1, U1.12 (RA4)
unnamed: C4.1, U1.20 (Vcap)
unnamed: C9.2, R4.2, R5.1, SW1.2
OSCI: C11.2, U1.9 (RA2), Y1.2
OSCO: C12.2, U1.10 (RA3), Y1.1
PGEC: J3.5, U1.5 (RB1)
PGED: J3.4, U1.4 (RB0)
U1RX: J4.3, U1.6 (RB2)
U1TX: J4.2, U1.7 (RB3)
Y: J1.3, U1.16 (RB7)
~MCLR: J3.1, R5.2, U1.1 (~MCLR)

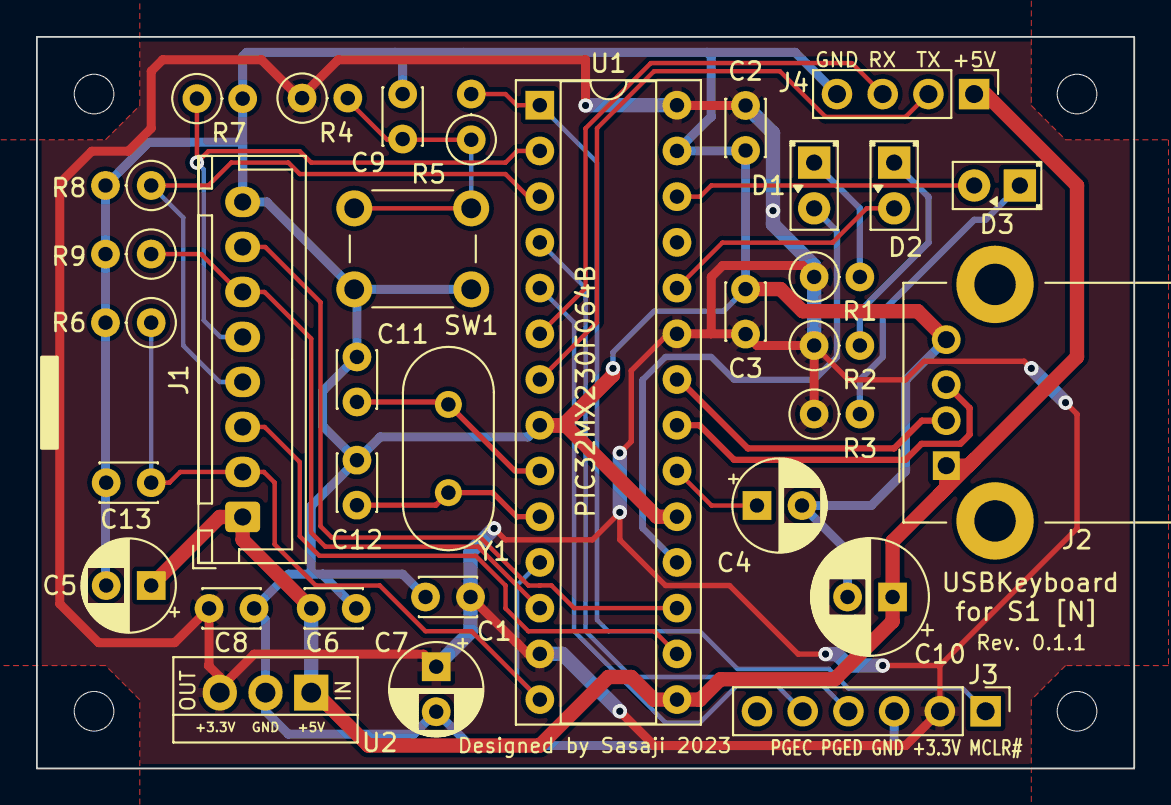
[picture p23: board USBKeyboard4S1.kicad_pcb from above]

Board: 2 copper layers, 61.0 x 40.6 mm, 33 parts (0 on the bottom side), 26 nets.

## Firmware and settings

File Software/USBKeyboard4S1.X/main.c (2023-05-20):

/*******************************************************************************
Copyright 2016 Microchip Technology Inc. (www.microchip.com)

Licensed under the Apache License, Version 2.0 (the "License");
you may not use this file except in compliance with the License.
You may obtain a copy of the License at

    http://www.apache.org/licenses/LICENSE-2.0

Unless required by applicable law or agreed to in writing, software
distributed under the License is distributed on an "AS IS" BASIS,
WITHOUT WARRANTIES OR CONDITIONS OF ANY KIND, either express or implied.
See the License for the specific language governing permissions and
limitations under the License.

To request to license the code under the MLA license (www.microchip.com/mla_license), 
please contact mla_licensing@microchip.com
*******************************************************************************/
/**
 * Modified by Sasaji at 2018/02/10
 */

/** INCLUDES *******************************************************/
#include <string.h>
#include "common.h"
#include "usb.h"
#include "usb_host_hid.h"
#include "usb_host_hub.h"

#include "system.h"
#include "app_host_hid_keyboard.h"
#include "timer_1ms.h"
#include "timer_2.h"
#include "interrupt.h"
#include "print_lcd.h"
#include "main.h"

uint8_t key_onoff_flags[20];
uint8_t led_hira_inv;

/****************************************************************************
  Function:
    int main(void)

  Summary:
    main function

  Description:
    main function

  Precondition:
    None

  Parameters:
    None

  Return Values:
    int - exit code for main function

  Remarks:
    None
  ***************************************************************************/
int main(void)
{   
    INTCONbits.MVEC = 1;
    INTCONbits.TPC = 0;
//    IPTMR = 50;
    __builtin_enable_interrupts();

    memset(key_onoff_flags, 0, sizeof(key_onoff_flags));
    led_hira_inv = 0;
//    key_onoff_flags[1] = 2;
    key_onoff_flags[0x71 >> 3] = (1 << (0x71 & 7));    // JIS Keyboard
    ANSELA = 0; // all digital
    ANSELB = 0; // all digital
    TRISB = ~(LAT_Y_N_MASK
        | LAT_BREAK_N_MASK
        | LAT_KATA_LED_MASK
        | LAT_HIRA_LED_MASK
        | LAT_CAPS_LED_MASK
    );
    ODCB = (LAT_Y_N_MASK
        | LAT_BREAK_N_MASK
    );
    LATBSET = (LAT_Y_N_MASK
        | LAT_BREAK_N_MASK
        | LAT_KATA_LED_MASK
        | LAT_HIRA_LED_MASK
    );
    LATBCLR = (LAT_CAPS_LED_MASK
    );

#ifdef DEBUG_ENABLE
    UART_Initialize();
#endif

    TIMER_SetConfiguration(TIMER_CONFIGURATION_1MS);
//    Timer2_Init();
    
    INTR_Init();
    
    //Initialize the stack
    USBHost();

    APP_HostHIDKeyboardInitialize();

    while(1)
    {
        USBHostTasks();
        USBHostHUBTasks();
        USBHostHIDTasks();

        //Application specific tasks
        APP_HostHIDKeyboardTasks();
        
#ifdef DEBUG_ENABLE
        UART_Tasks();
#endif
        // BREAK key
        if (key_onoff_flags[16] & 1) {
            LAT_BREAK_N_SET;
        } else {
            LAT_BREAK_N_CLR;
        }
    }//end while
}//end main



/****************************************************************************
  Function:
    bool USB_ApplicationEventHandler( uint8_t address, USB_EVENT event,
                void *data, uint32_t size )

  Summary:
    This is the application event handler.  It is called when the stack has
    an event that needs to be handled by the application layer rather than
    by the client driver.

  Description:
    This is the application event handler.  It is called when the stack has
    an event that needs to be handled by the application layer rather than
    by the client driver.  If the application is able to handle the event, it
    returns true.  Otherwise, it returns false.

  Precondition:
    None

  Parameters:
    uint8_t address    - Address of device where event occurred
    USB_EVENT event - Identifies the event that occured
    void *data      - Pointer to event-specific data
    uint32_t size      - Size of the event-specific data

  Return Values:
    true    - The event was handled
    false   - The event was not handled

  Remarks:
    The application may also implement an event handling routine if it
    requires knowledge of events.  To do so, it must implement a routine that
    matches this function signature and define the USB_HOST_APP_EVENT_HANDLER
    macro as the name of that function.
  ***************************************************************************/
bool USB_HOST_APP_EVENT_HANDLER ( uint8_t address, USB_EVENT event, void *data, uint32_t size )
{
    switch( (int)event )
    {
        /* Standard USB host events ******************************************/
        case EVENT_VBUS_REQUEST_POWER:
        case EVENT_VBUS_RELEASE_POWER:
        case EVENT_UNSUPPORTED_DEVICE:
        case EVENT_CANNOT_ENUMERATE:
        case EVENT_CLIENT_INIT_ERROR:
        case EVENT_OUT_OF_MEMORY:
        case EVENT_UNSPECIFIED_ERROR:
            return true;
            break;

        /* HUB Class Specific Events ******************************************/
        case EVENT_HUB_ATTACH:
            return true;
            break;

        /* HID Class Specific Events ******************************************/
        case EVENT_HID_RPT_DESC_PARSED:
            if(APP_HostHIDKeyboardReportParser() == true)
            {
                return true;
            }
            break;

        default:
            break;
    }

    return false;

}

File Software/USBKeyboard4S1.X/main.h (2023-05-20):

/** @file   main.h
 *
 *  @author Sasaji
 *  @date   2018/02/10
 *
 * 	@brief  main 
 */

#ifndef MAIN_H_
#define	MAIN_H_

#include <stdint.h>

#define PORT_HPP_IS_HIGH    ((PORTB & _PORTB_RB4_MASK) != 0)

#define PORT_KRES1_IS_SET   ((PORTA & _PORTA_RA0_MASK) == 0)
#define PORT_KRES2_IS_SET   ((PORTA & _PORTA_RA1_MASK) == 0)

#define PORT_LED_IS_LOW     ((PORTA & _PORTA_RA4_MASK) == 0)

//#define COUNTER_IS_ODD      ((TMR2 & 1) != 0)
//#define COUNTER_IS_EVEN     ((TMR2 & 1) == 0)

#define TRIS_Y_N            TRISBCLR = _TRISB_TRISB7_MASK
#define LAT_Y_N             LATBbits.LATB7
#define LAT_Y_N_MASK        _LATB_LATB7_MASK
#define LAT_Y_N_SET         LATBCLR = _LATB_LATB7_MASK
#define LAT_Y_N_CLR         LATBSET = _LATB_LATB7_MASK

#define TRIS_BREAK_N        TRISBCLR = _TRISB_TRISB8_MASK
#define LAT_BREAK_N_MASK    _LATB_LATB8_MASK
#define LAT_BREAK_N_SET     LATBCLR = _LATB_LATB8_MASK
#define LAT_BREAK_N_CLR     LATBSET = _LATB_LATB8_MASK

#define LAT_KATA_LED        LATBbits.LATB9
#define LAT_KATA_LED_MASK   _LATB_LATB9_MASK
#define LAT_KATA_LED_SET    LATBCLR = _LATB_LATB9_MASK
#define LAT_KATA_LED_CLR    LATBSET = _LATB_LATB9_MASK

#define LAT_HIRA_LED        LATBbits.LATB13
#define LAT_HIRA_LED_MASK   _LATB_LATB13_MASK
#define LAT_HIRA_LED_SET    LATBCLR = _LATB_LATB13_MASK
#define LAT_HIRA_LED_CLR    LATBSET = _LATB_LATB13_MASK

#define LAT_CAPS_LED        LATBbits.LATB15
#define LAT_CAPS_LED_MASK   _LATB_LATB15_MASK
#define LAT_CAPS_LED_SET    LATBCLR = _LATB_LATB15_MASK
#define LAT_CAPS_LED_CLR    LATBSET = _LATB_LATB15_MASK

extern uint8_t key_onoff_flags[20];
//extern bool key_pressed;
extern uint8_t led_hira_inv;

#endif	/* MAIN_H_ */

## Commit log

2023-05-20 Initial version
    [Board.fzz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]
2023-05-26 Revision 0.1
    [USBKeyboard4S1.kicad_pcb]
2023-10-21 Hardware version 0.1.1
    [USBKeyboard4S1-B_Cu.gbl, USBKeyboard4S1-B_Mask.gbs, USBKeyboard4S1-Edge_Cuts.gm1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]
